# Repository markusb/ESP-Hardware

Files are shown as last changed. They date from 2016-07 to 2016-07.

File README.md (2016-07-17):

<H1>ESP-Hardware</H1>
<p>This repository contains my collection of ESP-Related hardware designs

<h2>ESP-8285 Miniboard</h2>

<p>Small DIL-size board for an ESP8285 Wifi microcontroller
<p>There already are a bunch of ESP boards and modules around, but the either add a full programming circuit or are modules with small pins to solder.
<p>This wants to combine the best of both, with standard 2.54mm pinheaders and easy programming, but on a separate board. So you plug in the programmer when you want to download firmware, but remove it when you don't need it anymore.
<ul>
<li>DIL size, plugs directly into a breadboard
<li>Breaks out all IO pins, not an arbitrary selection like most modules
<li>Antenna and crystal on board, ready to, just add power
<li>Optional red power and blue tx LED, to see whats going on, can be removed to save power
<li>No other, potentially unwanted hardware to get in the way of your design
</ul>

<h2>ESP82xx Programmer</H2>
<p>USB programmer built for the ESP-Miniboard, but it will work for normal ESP82xx circuits and most modules as well.
<p>As the ESP-Miniboard has no programmer, you need it separately. So it goes on this second board, to be removed when no longer in use.
<ul>
<li>USB-Serial chip (CH340)
<li>3.3V Regulator to feed the ESP from USB during programming (no external power needed)
<li>3.3V supply has a jumper to disable power and a polyfuse to protect from a short
<li>Nodemcu reset circuit to decouple the RTS/DTR lines from reset and GPIO0
<li>Works with any ESP module, just connect up the pins and off you go !
</ul>

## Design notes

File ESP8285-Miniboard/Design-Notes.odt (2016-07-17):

Random design notes about the ESP miniboard and programmer

Programming procedure from ESP8266 System Description

Preparation:

- Power 3.3V

- Set EN Pin High

- Connect Gnd, RxD, TxD

Programming:

- Pull IO15 and IO0 low

- Leave IO2 open

-Download program to flash

- Keep IO2 open

- Pull IO0 high

References

- ESP-8285 datasheet
- ESP-8266 datasheet
- Arduino ESP8266 documentation: https://github.com/esp8266/Arduino/blob/master/doc/boards.md
- Seeed-OPL part library: http://www.seeedstudio.com/depot/OPLopen-parts-library-catalog-c-136_138/

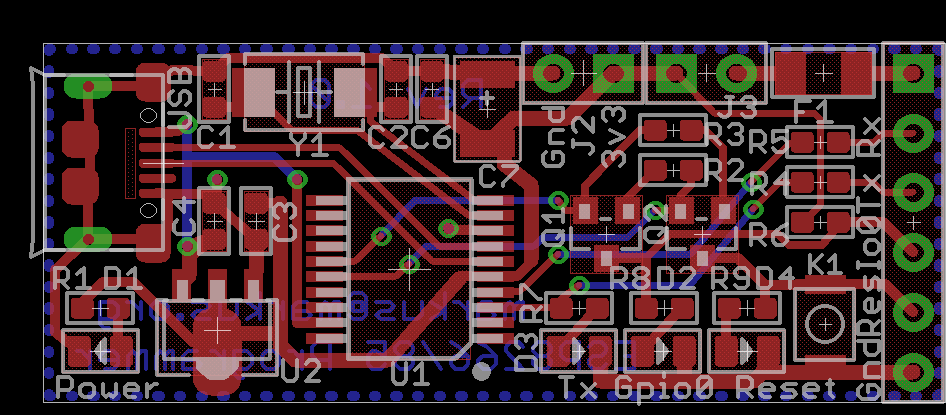
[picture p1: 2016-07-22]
ESP8285-Programmer/esp8285-programmer-v1.0-brd.png

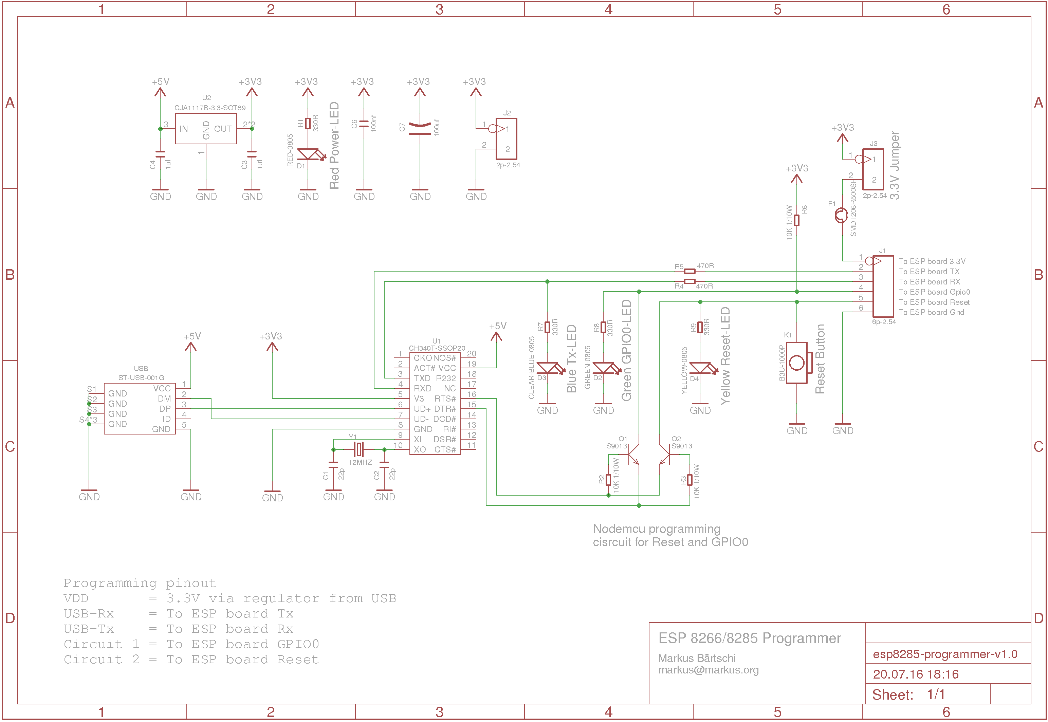
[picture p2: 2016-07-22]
ESP8285-Programmer/esp8285-programmer-v1.0-sch.png

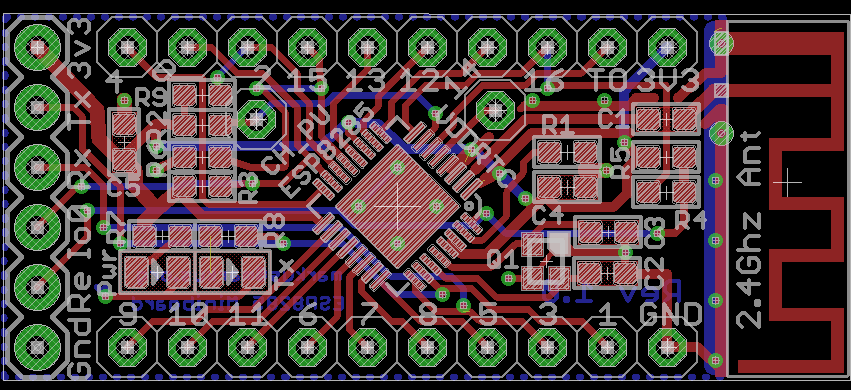
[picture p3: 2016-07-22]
ESP8285-Miniboard/esp8285-miniboard-v1.0-brd.png

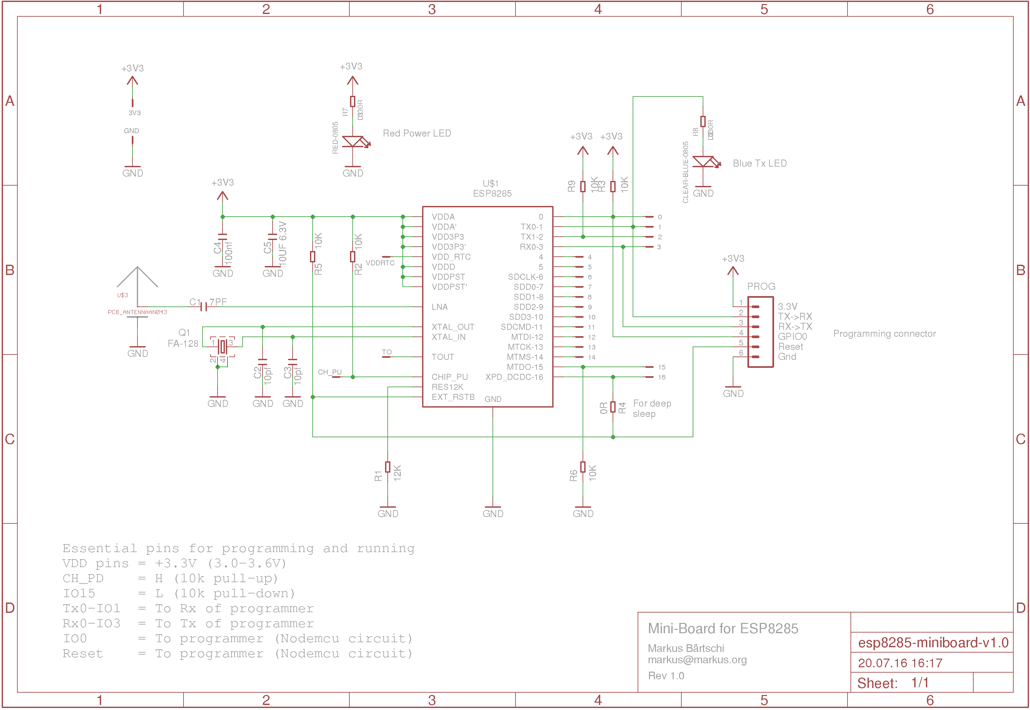
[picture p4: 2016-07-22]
ESP8285-Miniboard/esp8285-miniboard-v1.0-sch.png

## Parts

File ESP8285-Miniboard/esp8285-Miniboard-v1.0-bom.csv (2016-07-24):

Part/Designator | Manufacture Part Number/Seeed SKU | Quantity | Description
C1 | 302010091 | 1 | 0603, 7pF
C2, C3 | 302010097 | 2 | 0603, 10pF
C4 | 302010138 | 1 | 0603, 100nF
C5 | 302020002 | 1 | 0603, 10uF
D1 | 304090046 | 1 | 0805, LED Red
D2 | 304090061 | 1 | 0805, LED Blue
R1 | 301010102 | 1 | 0603, 12k
R2, R3, R5, R6, R9 | 301010299 | 5 | 0603, 10k
R7, R8, R4 | 301010300 | 2 | 0603, 330

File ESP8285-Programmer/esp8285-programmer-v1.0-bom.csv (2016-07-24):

Part/Designator | Manufacture Part Number/Seeed SKU | Quantity | Description
C1, C2 | 302010143 | 2 | 302010143, 0603, 22pF
C3, C4 | 302010139 | 2 | 302010139, 0603, 1uF
C6, C7 | 302010138 | 2 | 302010138, 0603, 100nF
D1 | 304090046 | 1 | 304090046, LED, 0805, Red
D2 | 304090057 | 1 | 304090057, LED, 0805, Green
D3 | 304090061 | 1 | 304090061, LED, 0805, Blue
D4 | 304090039 | 1 | 304090039, LED, 0805, Yellow
F1 | 307010002 | 1 | 307010002, Fuse, 1206, 500mA
K1 | 311020047 | 1 | 311020047, Button
Q1, Q2 | 305010018 | 2 | 305010018, Transistor, SOT23
R1, R7, R8, R9 | 301010300 | 4 | 301010300, Res 330, 0603
R2, R3, R6 | 301010299 | 3 | 301010299, Res 10k, 0603
R4, R5 | 301010088 | 2 | 301010088, Res 470, 0603
U1 | 310070026 | 1 | 310070026, CH340T USB serial
U2 | 310030095 | 1 | 310030095, CJA1117B-3.3 Regulator
USB | 320010000 | 1 | 320010000, USB Conn
Y1 | 306010047 | 1 | 306010047, 12Mhz Crystal

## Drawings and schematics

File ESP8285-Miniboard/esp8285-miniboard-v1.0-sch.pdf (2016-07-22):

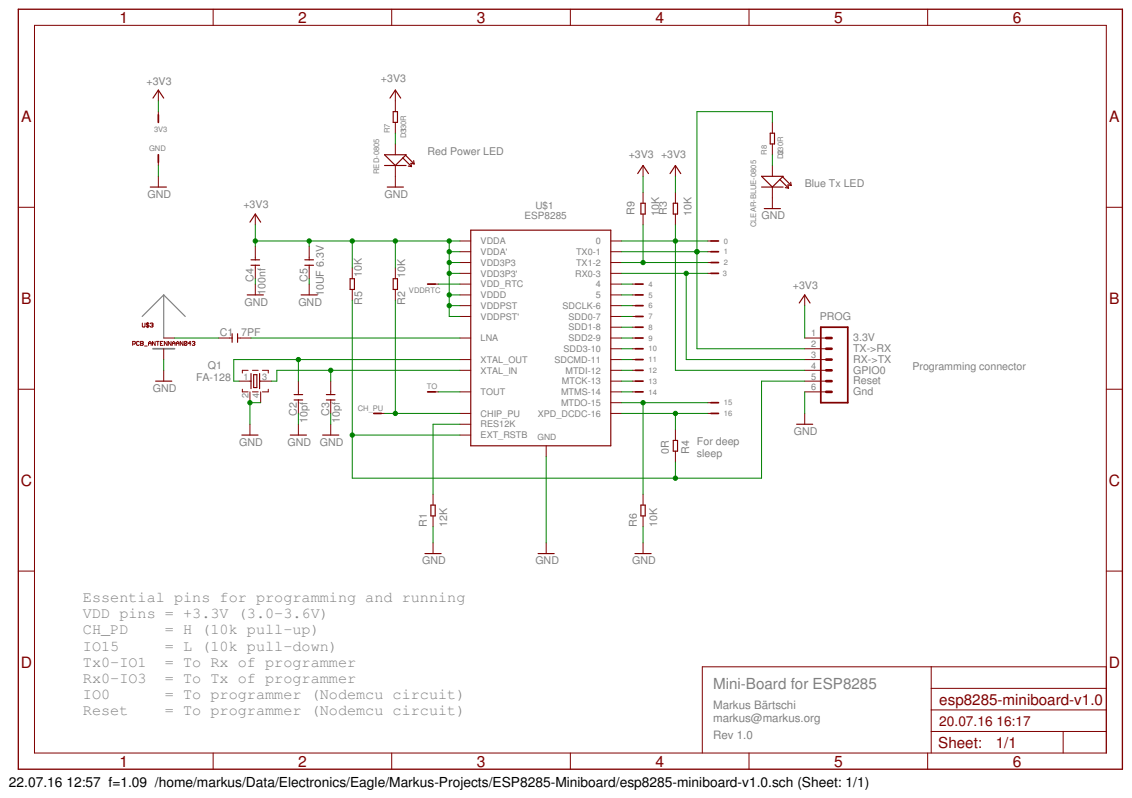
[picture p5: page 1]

Essential pins for programming and running
VDD pins = +3.3V (3.0-3.6V)
Tx0-IO1 = To Rx of programmer
Rx0-IO3 = To Tx of programmer

Mini-Board for ESP8285 Markus Bärtschi markus@markus.org Rev 1.0

Sheet: 1/1

22.07.16 12:57 f=1.09 /home/markus/Data/Electronics/Eagle/Markus-Projects/ESP8285-Miniboard/esp8285-miniboard-v1.0.sch (Sheet: 1/1)

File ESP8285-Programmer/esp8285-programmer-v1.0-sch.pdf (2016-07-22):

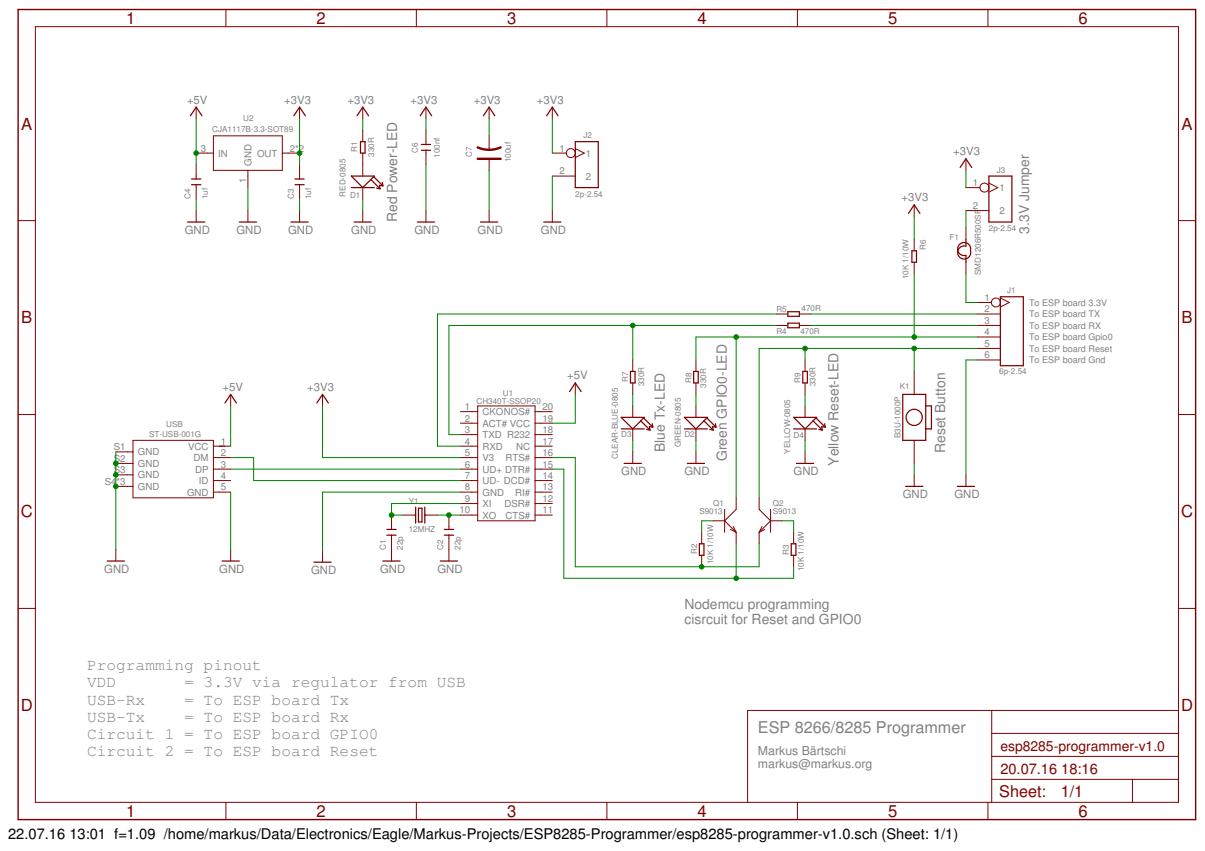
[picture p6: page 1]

To ESP board 3.3V
To ESP board TX
To ESP board RX
To ESP board Gpio0
To ESP board Reset To ESP board Gnd

Nodemcu programming
cisrcuit for Reset and GPIO0

Programming pinout
Circuit 1 = To ESP board GPIO0
Circuit 2 = To ESP board Reset

ESP 8266/8285 Programmer Markus Bärtschi markus@markus.org

Sheet: 1/1

22.07.16 13:01 f=1.09 /home/markus/Data/Electronics/Eagle/Markus-Projects/ESP8285-Programmer/esp8285-programmer-v1.0.sch (Sheet: 1/1)

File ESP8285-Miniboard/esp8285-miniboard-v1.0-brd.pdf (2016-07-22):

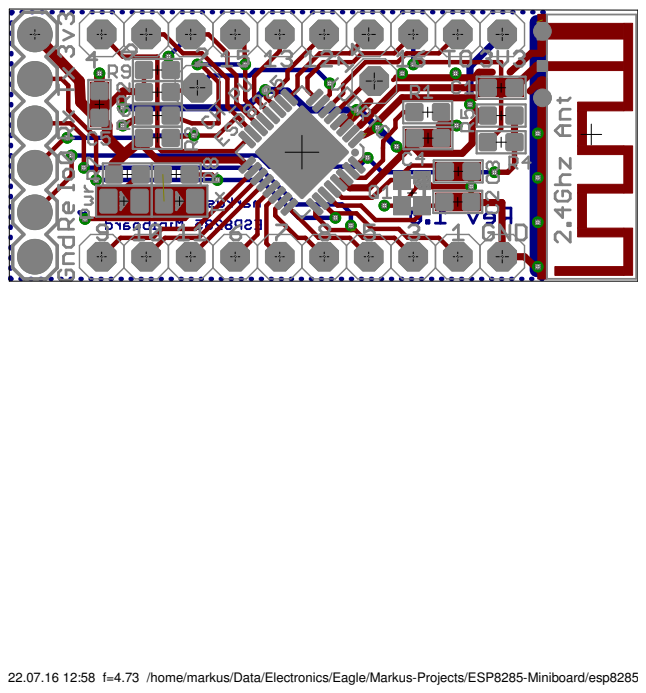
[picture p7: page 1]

22.07.16 12:58 f=4.73 /home/markus/Data/Electronics/Eagle/Markus-Projects/ESP8285-Miniboard/esp8285

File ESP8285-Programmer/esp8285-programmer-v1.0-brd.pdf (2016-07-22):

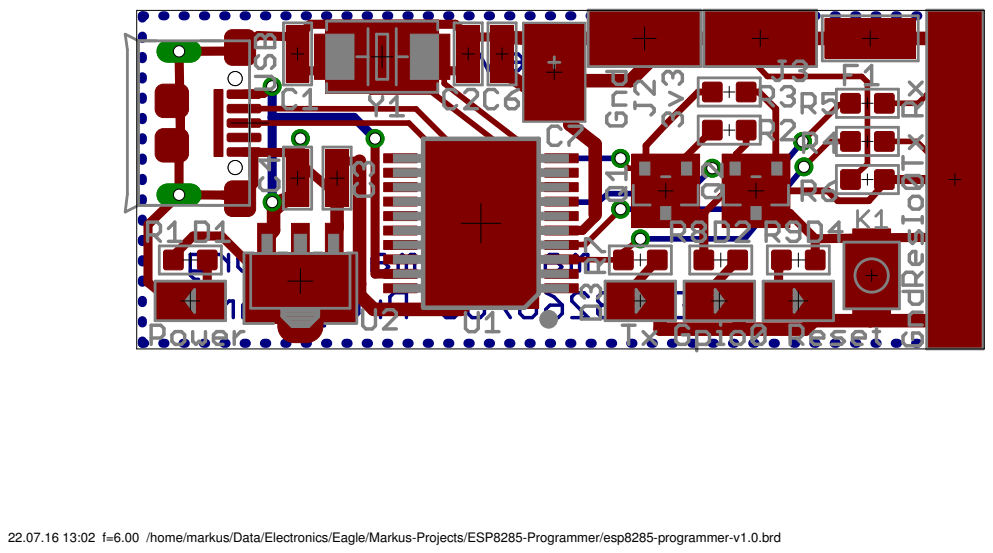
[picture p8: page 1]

22.07.16 13:02 f=6.00 /home/markus/Data/Electronics/Eagle/Markus-Projects/ESP8285-Programmer/esp8285-programmer-v1.0.brd

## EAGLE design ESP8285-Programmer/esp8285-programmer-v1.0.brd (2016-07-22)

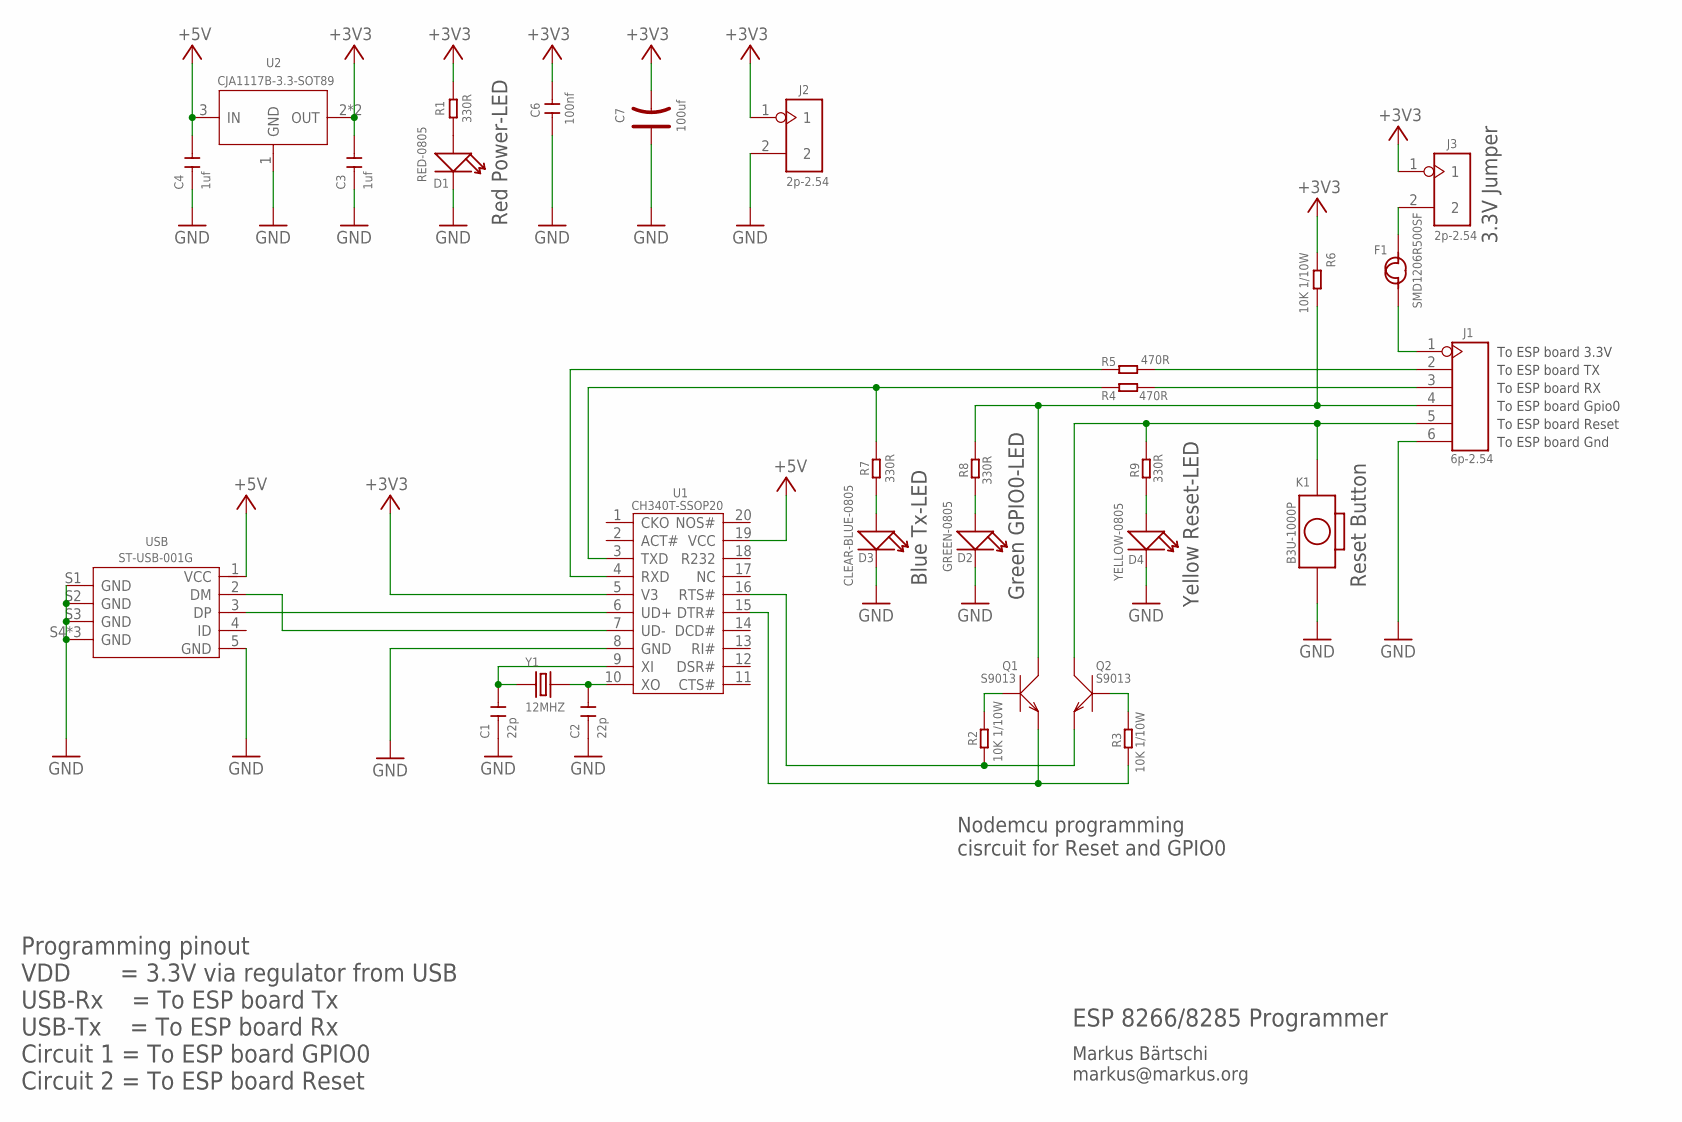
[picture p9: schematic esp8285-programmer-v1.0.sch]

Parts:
C1, C2: 22p; C0603
C3, C4: 1uf; C0603
C6: 100nf; C0603
C7: 100uf; AVX-B
D1: RED-0805; LED-0805
D2: GREEN-0805; LED-0805
D3: CLEAR-BLUE-0805; LED-0805
D4: YELLOW-0805; LED-0805
F1: SMD1206R500SF; F1206
J1: 6p-2.54; H6-2.54
J2, J3: 2p-2.54; H2-2.54
K1: B3U-1000P; SW2-SMD-3.0X2.5X1.2+0.4MM
Q1, Q2: S9013; SOT-23
R1, R7, R8, R9: 330R; R0603
R2, R3, R6: 10K 1/10W; R0603
R4, R5: 470R; R0603
U1: CH340T-SSOP20; SSOP20-0.65-7.6X5.2MM
U2: CJA1117B-3.3-SOT89; SOT-89
USB: ST-USB-001G; MICRO-USB5+4P-SMD-0.65-B
Y1: 12MHZ; X2-SMD-5.0X3.2X1.3MM

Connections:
+3V3: C3.2, C6.2, C7.-, J2.1, J3.1, R1.2, R6.1, U1.5 (V3), U2.2 (OUT), U2.4 (OUT)
+5V: C4.2, U1.19 (VCC), U2.3 (IN), USB.1 (VCC)
GND: C1.1, C2.1, C3.1, C4.1, C6.1, C7.+, D1.-, D2.-, D3.-, D4.-, J1.6, J2.2, K1.1, U1.8 (GND), U2.1 (GND), USB.5 (GND), USB.S1 (GND), USB.S2 (GND), USB.S3 (GND), USB.S4 (GND), USB.S5 (GND), USB.S6 (GND)
unnamed: F1.1, J1.1
unnamed: D1.+, R1.1
unnamed: F1.2, J3.2
unnamed: J1.2, R5.2
unnamed: C2.2, U1.10 (XO), Y1.2
unnamed: C1.2, U1.9 (XI), Y1.1
unnamed: J1.3, R4.2
unnamed: Q1.1 (B), R2.1
unnamed: Q2.1 (B), R3.1
unnamed: D3.+, R7.1
unnamed: D2.+, R8.1
unnamed: D4.+, R9.1
N$DTR: Q1.2 (E), R3.2, U1.15 (DTR#)
N$GPIO0: J1.4, Q1.3 (C), R6.2, R8.2
N$RESET: J1.5, K1.2, Q2.3 (C), R9.2
N$RTS: Q2.2 (E), R2.2, U1.16 (RTS#)
N$RX: R5.1, U1.4 (RXD)
N$TX: R4.1, R7.2, U1.3 (TXD)
N$USBD+: U1.6 (UD+), USB.3 (DP)
N$USBD-: U1.7 (UD-), USB.2 (DM)

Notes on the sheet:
Programming pinout VDD = 3.3V via regulator from USB USB-Rx = To ESP board Tx USB-Tx = To ESP board Rx Circuit 1 = To ESP board GPIO0 Circuit 2 = To ESP board Reset
To ESP board 3.3V
To ESP board TX
To ESP board RX
To ESP board Gpio0
To ESP board Reset
To ESP board Gnd
ESP 8266/8285 Programmer
Markus Bärtschi markus@markus.org
Nodemcu programming cisrcuit for Reset and GPIO0
Red Power-LED
Blue Tx-LED
Green GPIO0-LED
Yellow Reset-LED
Reset Button
3.3V Jumper

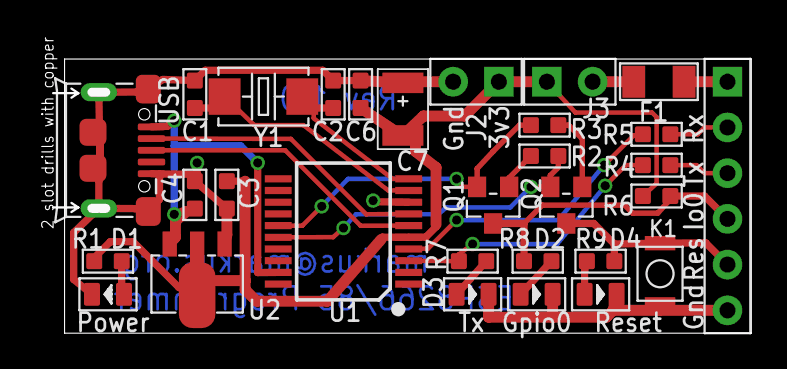
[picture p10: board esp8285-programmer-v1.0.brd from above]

Board: 2 copper layers, 38.8 x 15.2 mm, 30 parts (0 on the bottom side), 23 nets.

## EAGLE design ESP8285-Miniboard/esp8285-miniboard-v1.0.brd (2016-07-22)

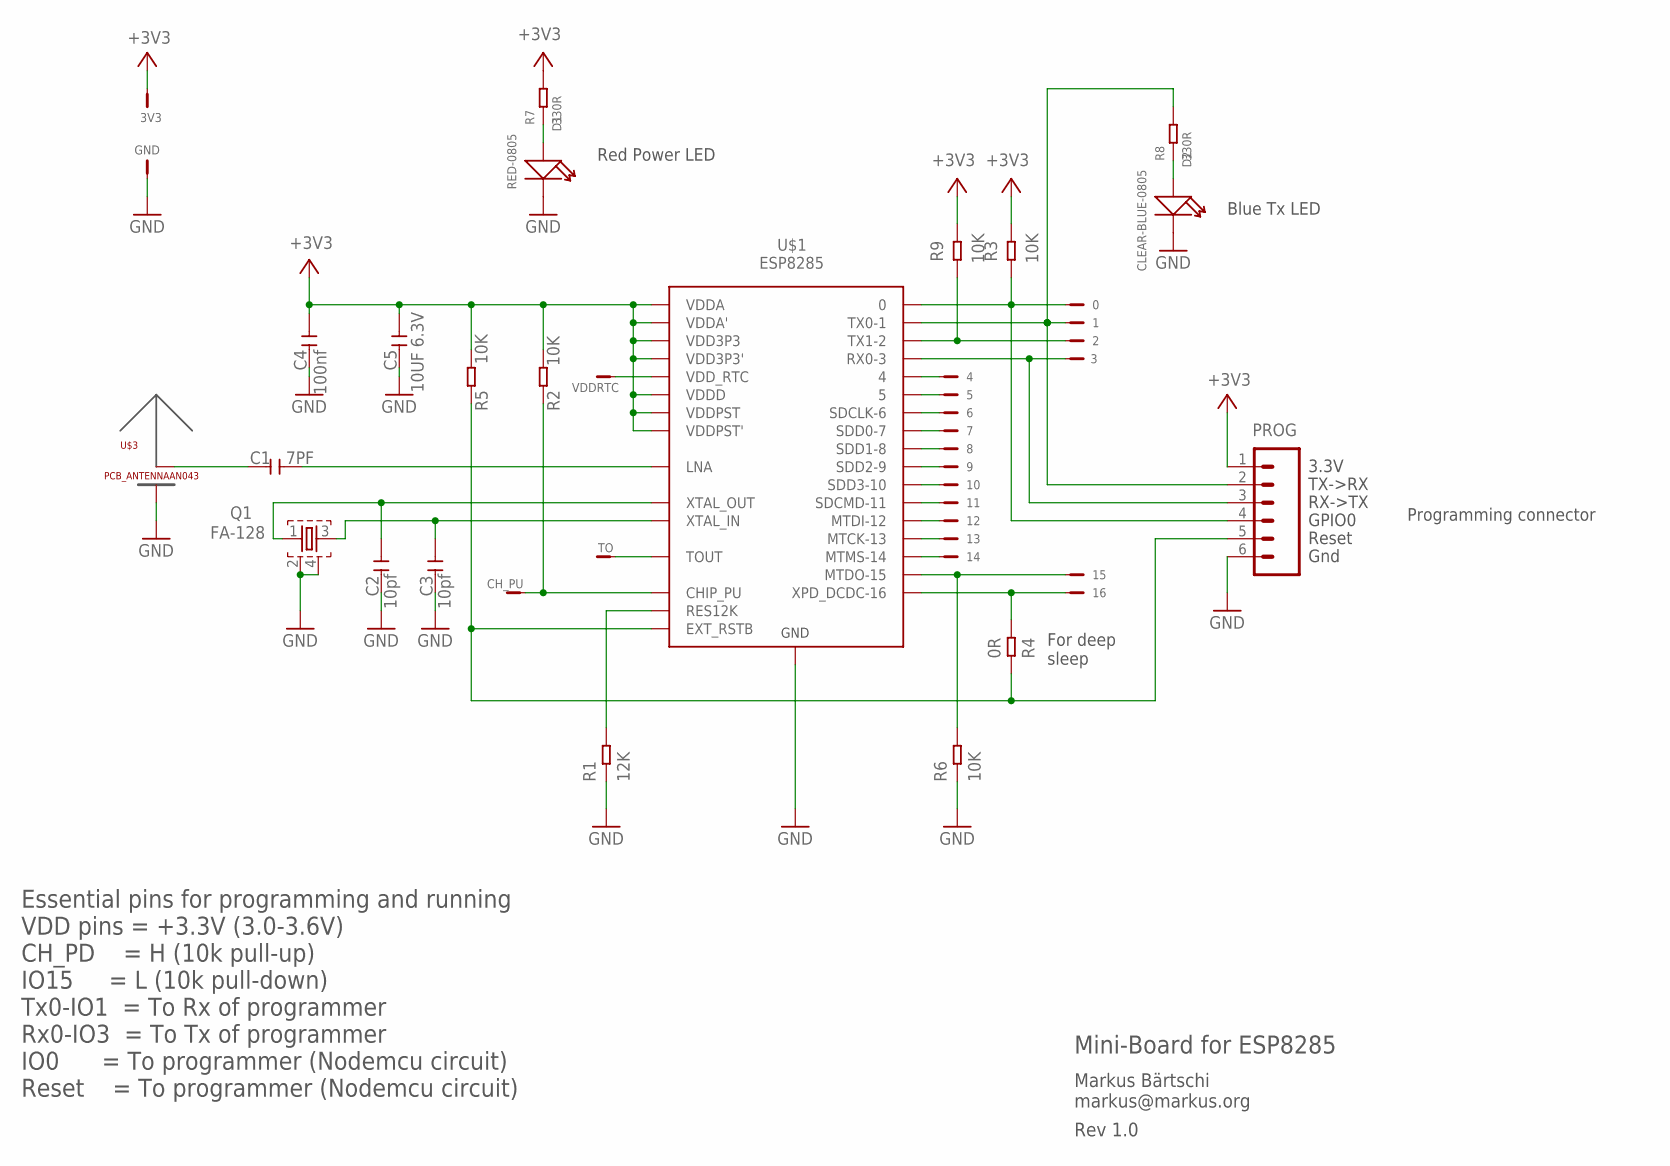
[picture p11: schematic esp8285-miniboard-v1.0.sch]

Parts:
0, 1, 2, 3, 3V3, 4, 5, 6, 7, 8, 9, 10, 11, 12, 13, 14, 15, 16: TESTPIN-1X1-SM; TESTPIN-HDR1X01
C1: 7PF; C0603
C2, C3: 10pf; C0603
C4: 100nf; C0603
C5: 10UF 6.3V; C0603
CH_PU: TESTPIN-1X1-SM; TESTPIN-HDR1X01
D1: RED-0805; LED-0805
D2: CLEAR-BLUE-0805; LED-0805
GND: TESTPIN-1X1-SM; TESTPIN-HDR1X01
PROG: M06SIP; 1X06
Q1: FA-128
R1: 12K; R0603
R2, R3, R5, R6, R9: 10K; R0603
R4: 0R; R0603
R7, R8: 330R; R0603
TO: TESTPIN-1X1-SM; TESTPIN-HDR1X01
U$1: ESP8285; QFN-32
U$3: PCB_ANTENNAAN043; PCB_ANTENNA_TI-AN043
VDDRTC: TESTPIN-1X1-SM; TESTPIN-HDR1X01

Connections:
+3V3: 3V3.1, C4.1, C5.1, PROG.1, R2.2, R3.2, R5.2, R7.2, R9.2, U$1.P$1 (VDDA), U$1.P$3 (VDD3P3), U$1.P$4 (VDD3P3'), U$1.P$11 (VDDPST), U$1.P$17 (VDDPST'), U$1.P$29 (VDDD), U$1.P$30 (VDDA')
GND: C2.1, C3.1, C4.2, C5.2, D1.-, D2.-, GND.1, PROG.6, Q1.2, Q1.4, R1.1, R6.1, U$1.33-GND (GND), U$3.GND
unnamed: D1.+, R7.1
unnamed: C1.1, U$3.ANT (AND)
unnamed: D2.+, R8.1
N$ANT: C1.2, U$1.P$2 (LNA)
N$CHIP_PU: CH_PU.1, R2.1, U$1.P$7 (CHIP_PU)
N$IO0: 0.1, PROG.4, R3.1, U$1.P$15 (0)
N$IO1: 1.1, PROG.2, R8.2, U$1.P$26 (TX0-1)
N$IO2: 2.1, R9.1, U$1.P$14 (TX1-2)
N$IO3: 3.1, PROG.3, U$1.P$25 (RX0-3)
N$IO4: 4.1, U$1.P$16 (4)
N$IO5: 5.1, U$1.P$24 (5)
N$IO6: 6.1, U$1.P$21 (SDCLK-6)
N$IO7: 7.1, U$1.P$22 (SDD0-7)
N$IO8: 8.1, U$1.P$23 (SDD1-8)
N$IO9: 9.1, U$1.P$18 (SDD2-9)
N$IO10: 10.1, U$1.P$19 (SDD3-10)
N$IO11: 11.1, U$1.P$20 (SDCMD-11)
N$IO12: 12.1, U$1.P$10 (MTDI-12)
N$IO13: 13.1, U$1.P$12 (MTCK-13)
N$IO14: 14.1, U$1.P$9 (MTMS-14)
N$IO15: 15.1, R6.2, U$1.P$13 (MTDO-15)
N$IO16: 16.1, R4.1, U$1.P$8 (XPD_DCDC-16)
N$RES12K: R1.2, U$1.P$31 (RES12K)
N$RESET: PROG.5, R4.2, R5.1, U$1.P$32 (EXT_RSTB)
N$TOUT: TO.1, U$1.P$6 (TOUT)
N$VDDRTC: U$1.P$5 (VDD_RTC), VDDRTC.1
N$XTAL-IN: C3.2, Q1.3, U$1.P$28 (XTAL_IN)
N$XTAL-OUT: C2.2, Q1.1, U$1.P$27 (XTAL_OUT)

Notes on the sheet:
Essential pins for programming and running VDD pins = +3.3V (3.0-3.6V) CH_PD = H (10k pull-up) IO15 = L (10k pull-down) Tx0-IO1 = To Rx of programmer Rx0-IO3 = To Tx of programmer IO0 = To programmer (Nodemcu circuit) Reset = To programmer (Nodemcu circuit)
3.3V
RX->TX
TX->RX
GPIO0
Reset
Gnd
Mini-Board for ESP8285
Rev 1.0
Markus Bärtschi markus@markus.org
Blue Tx LED
Red Power LED
For deep sleep
Programming connector

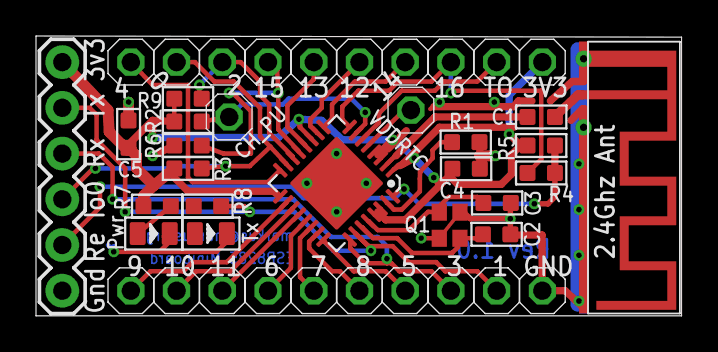
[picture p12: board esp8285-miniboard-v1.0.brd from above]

Board: 2 copper layers, 35.9 x 15.5 mm, 42 parts (0 on the bottom side), 30 nets.

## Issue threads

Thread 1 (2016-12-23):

There is an error on Schematic of programmer

AnalogLamb, 2016-12-23:
Hi,
CH340T's VCC connecting +5V is an error, We need to connect CH340T's VCC to +3.3V. Because V3 pin is connecting external +3.3V. And V3 pin's define as below:

![Uploading 截图01.jpg…]()

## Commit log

2016-07-17 Initial Rev 1
    [esp8285-miniboard-v1.0.brd, esp8285-miniboard-v1.0.sch, esp8285-programmer-v1.0.brd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]
2016-07-17 Another Rev 1.0
    [esp8285-miniboard-v1.0.brd, esp8285-miniboard-v1.0.sch, esp8285-programmer-v1.0.brd]
2016-07-19 Hopefully final V1.0
    [esp8285-miniboard-v1.0.GBL, esp8285-miniboard-v1.0.GBO, esp8285-miniboard-v1.0.GBP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]
2016-07-22 Final v1.0 fixed silkscreen, added testpoint, reduced via size
    [esp8285-miniboard-v1.0.GBL, esp8285-miniboard-v1.0.GBO, esp8285-miniboard-v1.0.GBP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]
2016-07-24 Added BOM in Seeed format
    [esp8285-Miniboard-v1.0-bom.csv, esp8285-programmer-v1.0-bom.csv]

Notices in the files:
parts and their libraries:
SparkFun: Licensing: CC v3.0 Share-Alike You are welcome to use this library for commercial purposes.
